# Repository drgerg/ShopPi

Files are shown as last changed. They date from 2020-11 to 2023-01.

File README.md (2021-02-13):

# ShopPi
 ### Shop Environmental Controls and Sensors

This is the newest node in my little PiNet.  It's also the least finished of the group. You might think it's ugly, and you'd be mostly right.  I have no intention of caring how it looks, only how it works.

I used an early Pi B+ and a Elegoo 8-relay board along with a DS18B20 W1 temp probe and a BME280 for sensors.  The BME280 is the primary sensor, the W1 probe is zip tied to the front grill of the window unit and can act as a comparison temperature source.

I learned it's a lot more difficult writing software to control cooling and heating of a room than I thought.  Honestly, I'm not sure I've done a very good job of it, but the window unit works, and 'thermostat.py' does it's job.  

I am planning to make substantive improvements, and consider this to be in the 'alpha' stages of development at this time (Dec 2020).

I have a separate relay-controlled electric space heater that I use to heat the shop.  ShopPi's relay board is hooked up in parallel with a standard cheap analog thermostat.  The analog thermostat now acts as a high temp safety. It's set for about 80F, so if ShopPi fails to turn the space heater off, the bimetal thermo will turn it off. It's a good backup to have.

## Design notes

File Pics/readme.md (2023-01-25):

# Pics

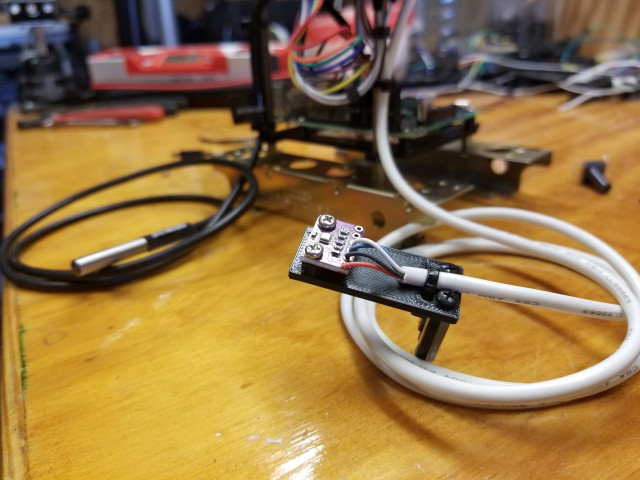
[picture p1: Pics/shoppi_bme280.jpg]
BME280 Module

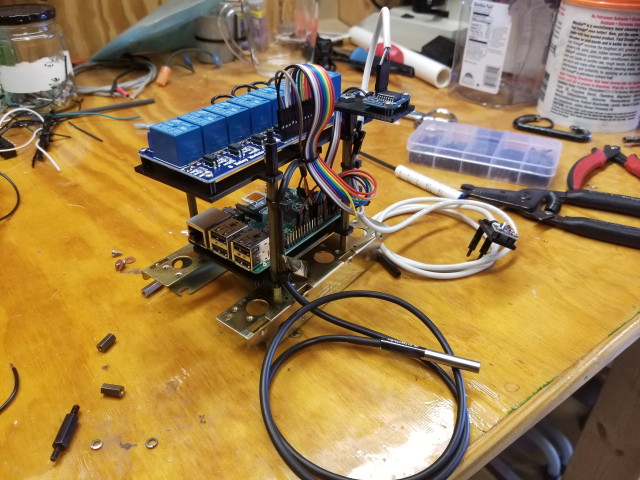
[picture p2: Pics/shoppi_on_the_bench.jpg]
ShopPi on the bench

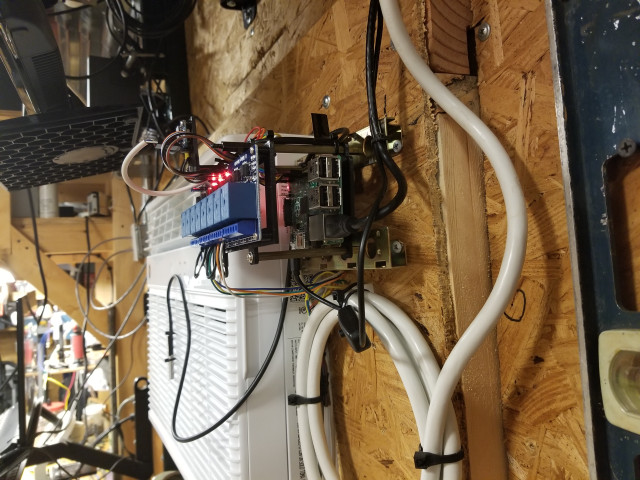
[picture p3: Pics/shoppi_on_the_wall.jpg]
ShopPi on the wall


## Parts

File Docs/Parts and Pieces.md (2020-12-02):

# Parts and Pieces

Raspberry Pi B+<br>
[Elegoo 8-Relay board](https://www.amazon.com/gp/product/B01HCFJC0Y/ref=ppx_yo_dt_b_search_asin_title?ie=UTF8&psc=1)<br>
[BME280 Temperature, Pressure, Humidity sensor](https://www.amazon.com/gp/product/B0118XCKTG/ref=ppx_yo_dt_b_search_asin_title?ie=UTF8&psc=1)<br>
[DS18B20 temperature probe](https://www.amazon.com/gp/product/B07RJMVY54/ref=ppx_yo_dt_b_search_asin_title?ie=UTF8&psc=1)<br>
[m2.5 x 6mm Self-tapping screws](https://www.amazon.com/gp/product/B01L7PDGXO/ref=ppx_yo_dt_b_search_asin_title?ie=UTF8&psc=1)<br>

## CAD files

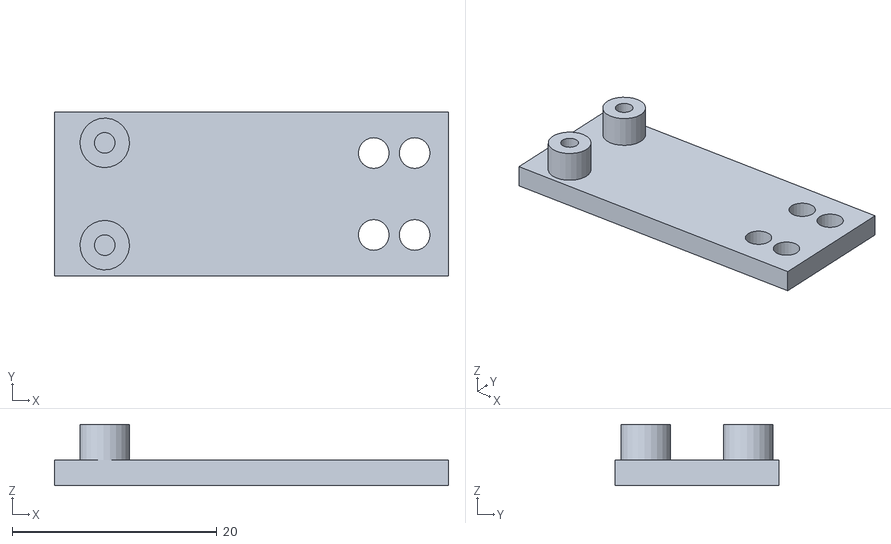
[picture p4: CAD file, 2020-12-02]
SKP-STL/BME280 flat mount.stl
38.5 x 16.0 x 5.99

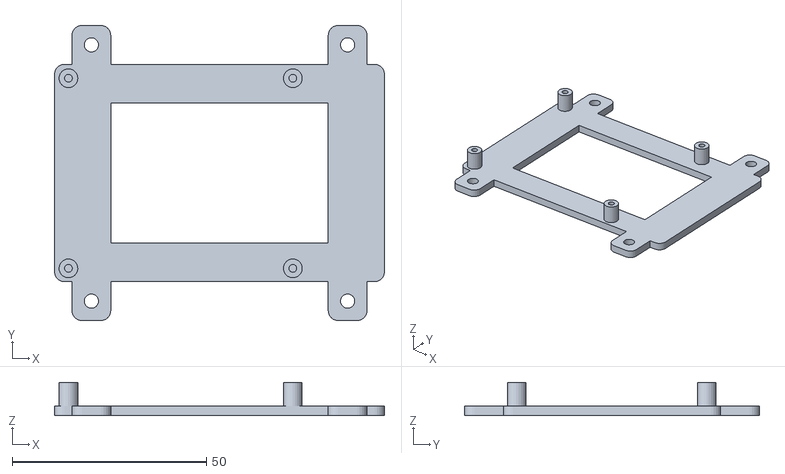
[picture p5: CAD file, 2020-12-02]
SKP-STL/Pi Mount 5 - 66mm x 4 - standoff frame.stl
85.0 x 76.0 x 8.50

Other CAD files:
SKP-STL/BME280 flat mount.skp
SKP-STL/Pi Mount 5 - 66mm x 4 - standoff frame.skp

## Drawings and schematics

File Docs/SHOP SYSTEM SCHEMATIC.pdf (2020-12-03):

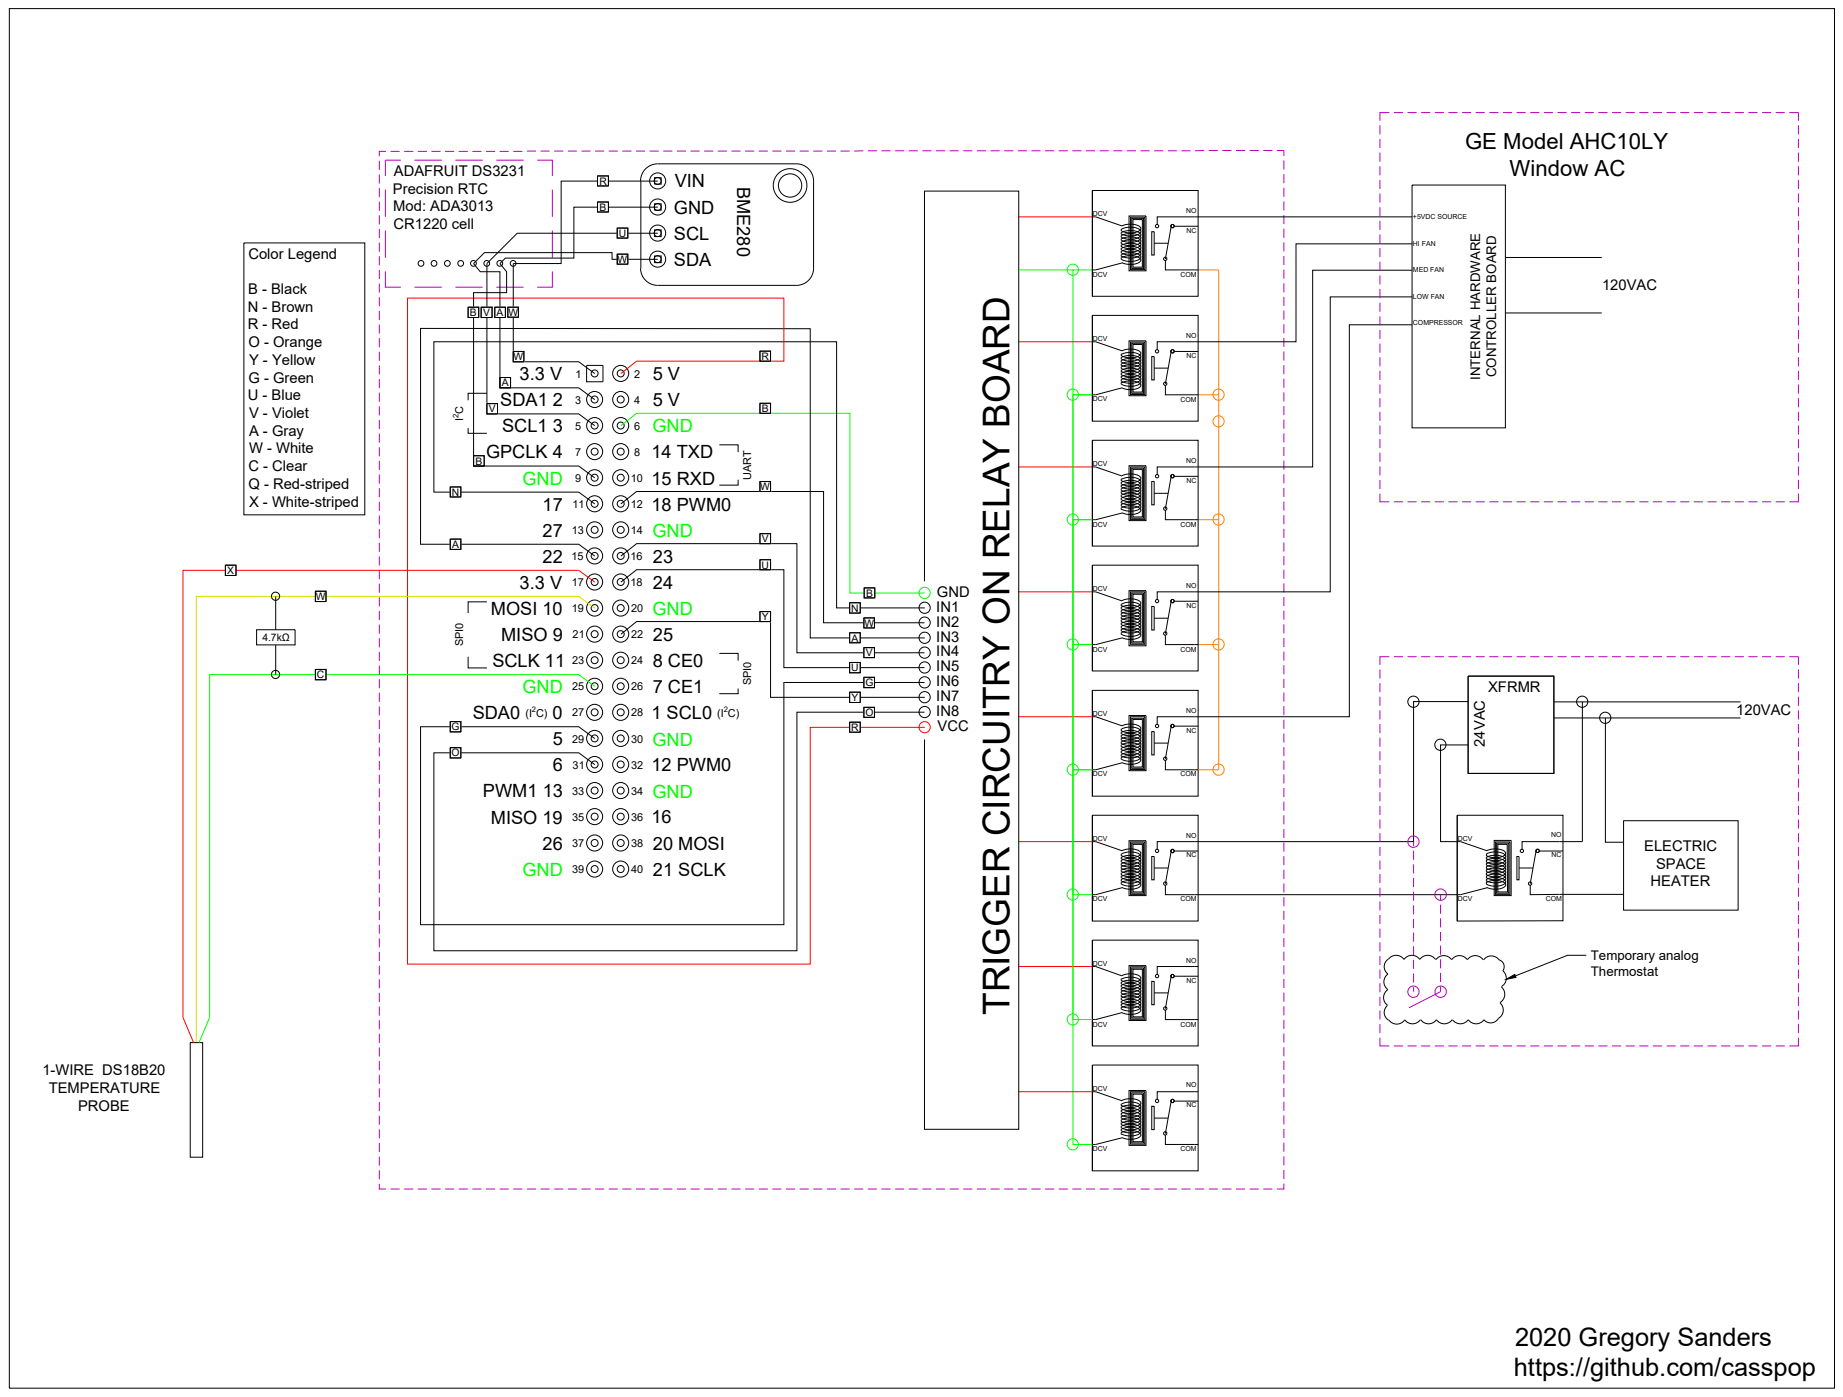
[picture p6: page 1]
+5VDC SOURCE COMPRESSOR LOW FAN MED FAN HI FAN NO DCV; COM DCV; NCNO DCV; NC 3.3 V SDA1 2 SCL1 3 GPCLK 4 GND172722 3.3 V MOSI 10 MISO 9 SCLK 11 GND SDA0 (I2C) 0; 6 PWM1 13 MISO 1926 GND; 5 V 5 V GND 14 TXD 15 RXD 18 PWM0 GND 2324GND 258 CE0 7 CE1 1 SCL0 (I2C) GND 12 PWM0 GND 1620 MOSI 21 SCLK; 2020 Gregory Sanders

INTERNAL HARDWARE CONTROLLER BOARD 120VAC 1-WIRE DS18B20 TEMPERATURE PROBE GE Model AHC10LY Window AC 4.7kΩ Mod: ADA3013 CR1220 cell Color Legend B - Black N - Brown R - Red O - Orange Y - Yellow G - Green U - Blue V - Violet A - Gray W - White C - Clear Q - Red-striped X - White-striped

TRIGGER CIRCUITRY ON RELAY BOARD GND IN1 IN2 IN3 IN4 IN5 IN6 IN7 IN8 VCC 120VAC ELECTRIC SPACE HEATER ADAFRUIT DS3231 Precision RTC

24VAC XFRMR Temporary analog Thermostat VIN GND SCL SDA

SPI0 I2C NO DCV COM DCV NC

https://github.com/casspop

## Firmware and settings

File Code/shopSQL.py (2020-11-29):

#!/usr/bin/env python3
#
""" shopSQL.py - Manage shopApp.py data logging.
    2019, 2020 - Gregory Allen Sanders"""

import os,sys,subprocess,configparser,logging,time,signal,mysql.connector,pickle,traceback,statistics,bme280,thermostat
from time import sleep
from mysql.connector import MySQLConnection, Error
import RPi.GPIO as GPIO
#
## ConfigParser init area.  Get some info out of working.conf.
#
#shopHome = os.getcwd()
shopHome = os.path.abspath(os.path.dirname(__file__))
config = configparser.RawConfigParser()
config.read(shopHome + '/shopApp.conf')
#
## End ConfigParser init

logger = logging.getLogger(__name__)

pklData = []
numBadPings = 0

def bme():

    s_outTemp = []
    s_pressure = []
    s_outHumidity = []
    s_rawHumidity = []
    tstart = time.time()

    while time.time() - tstart < 2:
        tempC,pres,humid,preHum = bme280.readBME280All()
        s_outTemp.append(tempC)
        s_pressure.append(pres)
        s_outHumidity.append(humid)
        s_rawHumidity.append(preHum)
    outTemp = statistics.mean(s_outTemp)
    pressure = statistics.mean(s_pressure)
    outHumidity = statistics.mean(s_outHumidity)
    extraHumid1 = statistics.mean(s_rawHumidity)

    return outTemp,pressure,outHumidity,extraHumid1

def getTemp(probe):

    probeSerial = config['Probes'][probe]
    probeName = config['ProbeNames'][probe + 'Name']
    probeAdjust = config['ProbeAdjust'][probe + 'Adjust']
    f = open('/sys/bus/w1/devices/' + probeSerial + '/w1_slave', 'r')
    line = f.readline()                 # read 1st line
    crc = line.rsplit(' ',1)
    crc = crc[1].replace('\n', '')
    if crc=='YES':
        line = f.readline()             # read 2nd line
        gettemp = line.rsplit('t=',1)
        gettemp = gettemp[1]
    else:
        gettemp = 99999
    f.close()
    tempC = (int(gettemp)/1000) + float(probeAdjust)
    tempF = '{:.2f}'.format(float(9/5 * tempC + 32.00))
    probeTemp = probeName +': ' + str(tempC) + '°C' + ' (' + str(tempF) + '°F)'

    return tempC,probeTemp

def datagrabber():
    tempC,probeTemp = getTemp('Probe1')
    shopTempF = '{:.2f}'.format(float(9/5 * tempC + 32.00))
    outTemp,pressure,outHumidity,extraHumid1 = bme()
    tempBMEF = '{:.2f}'.format(float(9/5 * outTemp + 32.00))
    humid = '{:.2f}'.format(float(outHumidity))
    ct = os.popen('vcgencmd measure_temp').readline()
    cpuRtn = ct.replace("temp=","").replace("'C\n","")
    cputemp1=float(cpuRtn)
    cputemp= '{:.2f}'.format(float(9/5 * cputemp1 + 32.00))
    return shopTempF,tempBMEF,humid,pressure,cputemp

#
##  mydb() COMPILE, CONTACT AND RECORD SHOP STATS TO MYSQL ON THE DATABASE SERVER
#
def mydb():
    global pklData,numBadPings
    # Get current values from all the sensors.
    shopTempF,tempBMEF,humid,pressure,cputemp = datagrabber()
    # Now make sure all the variables are of the right type.  Take no chances.
    shoptemp = float(shopTempF)
    tempbmef = float(tempBMEF)
    shophumid = float(humid)
    shoppress = float(pressure)
    shopcpu = float(cputemp)
    dtNow = int(time.time())
    dataTable = [dtNow,shoptemp,tempbmef,shophumid,shoppress,shopcpu]            # Put all the readings into a list.
    if os.path.exists(shopHome + '/shopData.pkl'):            ## This .pkl file will exist if the upcoming ping test failed last time around.
        pklData = pickle.load(open(shopHome + '/shopData.pkl', 'rb'))
    pklData.append(dataTable)                                 ## Merge the recent data with the .pkl file data just in case we are still offline
    logger.debug('dataTable was appended to pklData')
    DBhost=config.get('mySQL','Address')                      # get the mySQL login data from our config file.
    DBuser=config.get('mySQL','User')
    DBpasswd=config.get('mySQL','Password')
    DBdatabase=config.get('mySQL','Database')
    DBtable=config.get('mySQL','Table1')
    # Don't stop now . . . keep going!!!
    ## Check to see if we can ping the machine mySQL is running on
    pingRes = subprocess.call(['/bin/ping', '-c', '1', DBhost], stdout=subprocess.DEVNULL)  ## Ping test to make sure the SQL machine is there.
    logger.debug("Ping for server returned: " + str(pingRes))
    if pingRes == 0:                                        # We are connected.  Move ahead.  If not, don't do any of this stuff.
        if numBadPings > 0:
            logger.info("Connection to SQL server machine restored.")
        numBadPings = 0                                     # Prep the data, and send it to the SQL machine.
        for row in pklData:                                 # Normally there will only be one row. UNLESS the network was down, 
            dtNow = row[0]                                  # in which case there can be many.
            shoptemp = row[1]
            tempbmef = row[2]
            shophumid = row[3]
            shoppress = row[4]
            shopcpu = row[5]
            DTNhuman = time.strftime("%a, %d %b %Y %H:%M:%S %Z", time.localtime(dtNow))
            logger.info(DTNhuman + ' PT:' + str(format(shoptemp,'.2f')) + ' T:' + str(format(tempbmef,'.2f')) + ' H:' + str(format(shophumid,'.2f')) + ' P:' + str(format(shoppress,'.2f')) + ' C:' + str(format(shopcpu,'.2f')))
######  TEMPORARY CODE SECTION BELOW  #########################################
            # if float(tempbmef) >= 79.0:
            #     thermostat.shopEnv('cool',77,3)
            #     logger.info('From shopSQL.py, mydb() Turned AC On.')
            # if float(tempbmef) < 77.0:
            #     thermostat.shopEnv('off',77,3)
            #     logger.info('From shopSQL.py, mydb() Turned AC Off.')
######  TEMPORARY CODE SECTION ABOVE  ########################################
            try:
                                                            # prepare the database connector 
                mydb = mysql.connector.connect(
                    host=DBhost,
                    user=DBuser,
                    passwd=DBpasswd,
                    database=DBdatabase
                )
                cursor = mydb.cursor()                      # Attempt a connection with the remote database. If it is not there, 
                cursor.execute("select database();")        # an exception will be logged and we will save our data for the 
                record = cursor.fetchone()                  # next go-round.
                logger.debug("Got the database: " + str(record))
                addRecord = ('INSERT INTO ' + DBdatabase + '.' + DBtable + '' \
                    ' (dateTime,shopTemp,shopTempBME,shopHumidity,shopPress,shopCPU)' \
                    ' VALUES (%s,%s,%s,%s,%s,%s)')
                addData = (dtNow,shoptemp,tempbmef,shophumid,shoppress,shopcpu)
                logger.debug(addRecord %addData)
                cursor.execute(addRecord,addData)
                cursor.execute("SELECT * FROM " + DBdatabase + '.' + DBtable + " where id=(select max(id) from " + DBdatabase + '.' + DBtable + ")")
                record = cursor.fetchone()
                logger.debug('The last record contains: ' + str(record))
                mydb.commit()
                cursor.close()
                mydb.close()
                pklData = []                                ## RESET pklData to an empty list.
                if os.path.exists(shopHome + '/shopData.pkl'):
                    os.remove(shopHome + '/shopData.pkl')
                    logger.debug("shopData.pkl Pickle file erased.")
            except Exception:
                logger.info('Unable to connect with mySQL database.  Details to follow: ', exc_info=True)
                pass
            funNStr = sys._getframe().f_code.co_name
            logger.debug("Finished the " + funNStr + " function")
    else:                                                    # We are NOT CONNECTED.  Save our readings to a .pkl file
        logger.info("Ping test for SQL server machine failed.")
        numBadPings += 1
        pickle.dump(pklData, open(shopHome + '/shopData.pkl', 'wb+'), pickle.HIGHEST_PROTOCOL)
        logger.debug("shopData.pkl updated.")
        logger.info ("Number of bad pings is: " + str(numBadPings) + ".")
        if numBadPings >= 3:
            logger.info("Too many bad pings.  Setting up to reboot.")
            os.mknod(shopHome + '/rebootItNow')
        
def SignalHandler(signal, frame):
    if signal == 2:
        sigStr = 'CTRL-C'
        logger.info('* * * ' + sigStr + ' caught. * * * ')
    print("SignalHandler invoked")
    logger.info("Shutting down gracefully")
    logger.debug("Wrote to log in SignalHandler")
    logger.info("That's all folks.  Goodbye")
    logger.info(" - - - - shopSQL.py DATA LOGGING STOPPED BY DESIGN - - - - ")
    logging.shutdown()
    sleep(2)
    sys.exit(0)
    
if __name__ == "__main__":
    try:
        GPIO.setmode(GPIO.BCM)
        GPIO.setwarnings(False)
        import argparse

        ## Command line arguments parsing
        #
        parserSsql = argparse.ArgumentParser()
        parserSsql.add_argument("-d", "--debug", help="Turn on debugging output to stderr", action="store_true")
        argsssql = parserSsql.parse_args()
        if argsssql.debug:
            logging.basicConfig(filename=shopHome + '/shopLog.log', format='[%(name)s]:%(levelname)s: %(message)s - %(asctime)s', datefmt='%D %H:%M:%S', level=logging.DEBUG)
            logging.info("Debugging output enabled")
        else:
            logging.basicConfig(filename=shopHome + '/shopLog.log', format='%(asctime)s - %(message)s', datefmt='%a, %d %b %Y %H:%M:%S', level=logging.INFO)
        #
        ## End Command line arguments parsing

        signal.signal(signal.SIGINT, SignalHandler)  ## This one catches CTRL-C from the local keyboard
        signal.signal(signal.SIGTERM, SignalHandler) ## This one catches the Terminate signal from the system    


        if os.path.isfile(shopHome + '/CurrentState.pkl'):
            try:
                with open(shopHome + '/CurrentState.pkl', 'rb') as pinPik:
                    Tpins = pickle.load(pinPik)
            except EOFError:
                logger.info("In getTemp(). Encountered an empty .pkl file.  Moving on without it.")
                os.remove(shopHome + '/CurrentState.pkl')
                os.system('cp ' + shopHome + '/InitialTpins.pkl ' + shopHome + '/CurrentState.pkl')
                pass
        else:
            os.system('cp ' + thermoHome + '/InitialTpins.pkl ' + thermoHome + '/CurrentState.pkl')
            with open(thermoHome + '/CurrentState.pkl', 'rb') as pinPik:
                Tpins = pickle.load(pinPik)
            for pin in Tpins:
                GPIO.setup(pin, Tpins[pin]['I-O'])
                GPIO.output(pin, Tpins[pin]['state'])
            


        logger.debug("Top of try")
        while True:
            logger.info(" - - - - shopSQL.py DATA LOGGING STARTED - - - - ")
            freq=config.get('mySQL','LogFreq')
            goTime = time.time() + int(freq)
            while True:
                if time.time() < goTime:
                    time.sleep(1)
                else:
                    try:
                        goTime = time.time() + int(freq)
                        mydb()
                    except Error as error:
                        logger.info(error)
                    pass
        logger.info("Bottom of try")

    except Exception:
        logger.info("Exception caught at bottom of try.", exc_info=True)
        error = traceback.print_exc()
        logger.info(error)
        logger.info("That's all folks.  Goodbye")
        logger.info(" - - - -shopSQL.py DATA LOGGING STOPPED BY EXCEPTION - - - - ")
        logging.shutdown()
        sleep(2)
        sys.exit(0)

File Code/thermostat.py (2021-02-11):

#!/usr/bin/env python3
#
# thermostat.py - DIY Heat/AC controller.
# Copyright (c) 2019,2020,2021 - Gregory Allen Sanders.

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
import os,sys,subprocess,configparser,time,signal,pickle,traceback,shopSQL,bme280,threading
import argparse,logging
from time import sleep
from collections import OrderedDict
import RPi.GPIO as GPIO
#
### - Main body of code starts here.
GPIO.setmode(GPIO.BCM)
GPIO.setwarnings(False)
thermoHome = os.path.abspath(os.path.dirname(__file__))

####  PINS PICKLE: A pickle file called CurrentState.pkl holds data on the current state of 
####               the GPIO pins that control various part of the system.
####               We first have to see if the file exists, and if not, create it.
####               CurrentState.pkl contains a dictionary named 'Tpins' which is made by OrderedDict()
####               from the normal dictionary named 'pins'. OrderedDict() gives us a sorted dictionary.
##
# We need a dictionary called 'Tpins'. It either exists in 'CurrentState.pkl' or we have to create it from scratch.
# If CurrentState.pkl exists, load it and extract the Tpins dictionary from it.
if os.path.isfile(thermoHome + '/CurrentState.pkl'):
    try:
        with open(thermoHome + '/CurrentState.pkl', 'rb') as pinPik:
            Tpins = pickle.load(pinPik)
    except EOFError:
        logger.debug("In main(). Encountered an empty .pkl file.  Moving on without it.")
        os.remove(thermoHome + '/CurrentState.pkl')
        os.system('cp ' + thermoHome + '/InitialTpins.pkl ' + thermoHome + '/CurrentState.pkl')
        pass
else:
    os.system('cp ' + thermoHome + '/InitialTpins.pkl ' + thermoHome + '/CurrentState.pkl')
    with open(thermoHome + '/CurrentState.pkl', 'rb') as pinPik:
        Tpins = pickle.load(pinPik)
#
### NOW actually use the contents of the dictionary 'Tpins' to set the GPIO pins.
#
# To initialize the hardware to an 'Off' state, set each pin as an output and make it HIGH (HIGH = off):
for pin in Tpins:
    GPIO.setup(pin, Tpins[pin]['I-O'])
    GPIO.output(pin, Tpins[pin]['state'])
#
# Tpar is a dictionary that holds all of our working variables. As a dictionary, it's a 'keyword:value' pair
# file format. We'll use this to carry these variables around from place to place as 'kwargs'.
# Tpar is saved to disk in the 'thermParms.pkl' file.  The next two lines read that into memory.
with open(thermoHome + '/thermParms.pkl', 'rb') as tpmR:
    Tpar = pickle.load(tpmR)
#
# showStatus() does what the name implies, it gathers info about the current state of affairs and 
# puts it in the log file as well as printing it to stdout.
def showStatus():
    tempC,probeTemp = shopSQL.getTemp('Probe1')
    logger = logging.getLogger(__name__)
    if os.path.isfile(thermoHome + '/CurrentState.pkl'):
        try:
            with open(thermoHome + '/CurrentState.pkl', 'rb') as pinPik:
                Tpins = pickle.load(pinPik)
        except EOFError:
            logger.debug("In main(). Encountered an empty .pkl file.  Moving on without it.")
            os.remove(thermoHome + '/CurrentState.pkl')
            pass
    for pin in Tpins:
        status = GPIO.input(pin)
        if status == 1:
            statStr = 'Off'
        if status == 0:
            statStr = 'On'
        logger.debug('Pin ' + str(pin) + ' ' + str(Tpins[pin]['name']) + ' is ' + statStr)
        print('Pin ' + str(pin) + ' ' + str(Tpins[pin]['name']) + ' is ' + statStr)
    logger.debug(probeTemp)
    print(probeTemp)
#
# newStat() is called when we want to change the status of outputs on the GPIO header.
#
def newStat(changePin, action):
    thermoHome = os.path.abspath(os.path.dirname(__file__))
    logger = logging.getLogger(__name__)
    if os.path.isfile(thermoHome + '/CurrentState.pkl'):
        try:
            with open(thermoHome + '/CurrentState.pkl', 'rb') as pinPik:
                Tpins = pickle.load(pinPik)
        except EOFError:
            logger.debug("In newStat(). Encountered an empty .pkl file.  Moving on without it.")
            os.remove(thermoHome + '/CurrentState.pkl') 
            pass
    # Convert the pin into an integer:
    changePin = int(changePin)
    # Get the device name for the pin being changed:
    deviceName = Tpins[changePin]['name']
    if action == "on":
        # Set the pin low. Toggle low pins high to keep only one low. HIGH is Off.:
        if changePin == 5:  # compressor
            GPIO.output(5, GPIO.LOW)
        if changePin == 18:  # Low Fan
            GPIO.output(22, GPIO.HIGH)
            GPIO.output(23, GPIO.HIGH)
            GPIO.output(25, GPIO.HIGH)
            GPIO.output(18, GPIO.LOW)
        if changePin == 22:  # Medium Fan
            GPIO.output(18, GPIO.HIGH)
            GPIO.output(23, GPIO.HIGH)
            GPIO.output(25, GPIO.HIGH)
            GPIO.output(22, GPIO.LOW)
        if changePin == 23:  # High Fan
            GPIO.output(18, GPIO.HIGH)
            GPIO.output(22, GPIO.HIGH)
            GPIO.output(25, GPIO.HIGH)
            GPIO.output(23, GPIO.LOW)
        if changePin == 25:  # Heater
            GPIO.output(18, GPIO.HIGH)
            GPIO.output(22, GPIO.HIGH)
            GPIO.output(23, GPIO.HIGH)
            GPIO.output(25, GPIO.LOW)
        if changePin == 24:  # Power (VCC for airconditioner internal circuits)
            GPIO.output(24, GPIO.LOW)
        message = "Turned " + deviceName + " on."

    if action == "off":      ## Put everything in a Off state.
        if changePin == 24:
            GPIO.output(5, GPIO.HIGH)
            GPIO.output(18, GPIO.HIGH)
            GPIO.output(22, GPIO.HIGH)
            GPIO.output(23, GPIO.HIGH)
            GPIO.output(24, GPIO.HIGH)
            GPIO.output(25, GPIO.HIGH)
            message = "System powered down."

        if changePin != 24:
            GPIO.output(changePin, GPIO.HIGH)
            message = "Turned " + deviceName + " off."
    # For each pin, read the pin state and store it in the pins dictionary:
    for pin in Tpins:
        Tpins[pin]['state'] = GPIO.input(pin)
    logger.debug('Pin ' + str(changePin) + ' ' + deviceName + ' ' + action)
    with open(thermoHome + '/CurrentState.pkl', 'wb+') as pinPikW:
        pickle.dump(Tpins, pinPikW, pickle.HIGHEST_PROTOCOL)
    logger.debug(message)
    return message
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

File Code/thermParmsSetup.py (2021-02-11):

#!/usr/bin/env python3
#
# A utility by Greg Sanders to set the initial state and save that into a pickle file.
# This utility creates a file named 'InitialTpins.pkl'.  If you want to reset the 
# initial settings, you will need to stop the shopThermo.service and delete 'CurrentState.pkl'.
# When you restart shopThermo.service, it'll load 'InitialTpins.pkl' into 'CurrentState.pkl'.
# To make an edit to InitialTpins.pkl, uncomment everything below "import os,pickle" and run './InitializePickle.py'.
# Afterwards, re-comment that block.  Then you can run it to set 'thermParms.pkl' only.
#
import os,pickle
# from collections import OrderedDict
# import RPi.GPIO as GPIO
# GPIO.setmode(GPIO.BCM)
# GPIO.setwarnings(False)
thermoHome = os.path.abspath(os.path.dirname(__file__))
# pins = {
#     18 : {'sort' : '1', 'name' : 'Fan Low', 'I-O' : GPIO.OUT, 'state' : GPIO.HIGH},
#     22 : {'sort' : '2', 'name' : 'Fan Medium', 'I-O' : GPIO.OUT, 'state' : GPIO.HIGH},
#     23 : {'sort' : '3', 'name' : 'Fan High', 'I-O' : GPIO.OUT, 'state' : GPIO.HIGH},
#     5 : {'sort' : '4', 'name' : 'Compressor', 'I-O' : GPIO.OUT, 'state' : GPIO.HIGH},
#     24 : {'sort' : '5', 'name' : 'Power', 'I-O' : GPIO.OUT, 'state' : GPIO.HIGH},
#     25 : {'sort' : '6', 'name' : 'Heat', 'I-O' : GPIO.OUT, 'state' : GPIO.HIGH}
#     }
#             # SAVE THIS DICTIONARY AS AN ORDERED DICTIONARY USING OrderedDict()
# Tpins = OrderedDict(sorted(pins.items(), key=lambda kv: kv[1]['sort']))
#             # SAVE THE NEW ORDERED DICTIONARY TO 'CurrentState.pkl'
# with open(thermoHome + '/InitialTpins.pkl', 'wb+') as pinPikW:
#     pickle.dump(Tpins, pinPikW, pickle.HIGHEST_PROTOCOL)
# # To initialize the hardware to an 'Off' state, set each pin as an output and make it HIGH (HIGH = off):
# for pin in Tpins:
#     GPIO.setup(pin, Tpins[pin]['I-O'])
#     GPIO.output(pin, Tpins[pin]['state'])

Tpar = {'SEMode':'off', 'SETemp':'80', 'SEFan':'0', 'STMode':'off', 'STTemp':'77', 'STFan':'0'}
with open(thermoHome + '/thermParms.pkl', 'wb+') as pinPikW:
    pickle.dump(Tpar, pinPikW, pickle.HIGHEST_PROTOCOL)

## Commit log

2020-12-02 flesh out repo
    [BME280 flat mount.skp, BME280 flat mount.stl, Pi Mount 5 - 66mm x 4 - standoff frame.skp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]
2020-12-03 Create SHOP SYSTEM SCHEMATIC.pdf
2020-12-03 Update SHOP SYSTEM SCHEMATIC.pdf

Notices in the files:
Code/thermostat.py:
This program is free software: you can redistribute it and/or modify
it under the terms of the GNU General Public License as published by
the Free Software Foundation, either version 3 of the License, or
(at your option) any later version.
